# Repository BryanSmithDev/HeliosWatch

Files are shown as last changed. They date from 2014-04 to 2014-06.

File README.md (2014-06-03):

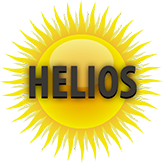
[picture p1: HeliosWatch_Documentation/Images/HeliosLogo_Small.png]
Helios
Helios Watch
==========
This project, dubbed Helios (God of Day/Night Cycle or God of the Sun), is based off of Tortuga's RetroWatch to create a Bluetooth enabled smartwatch using an Arduino that will pair with your Android device. Once paired, the smart watch can not only display the time and date, but notifications from your Android device as well. Additionally, the the watch can also display RSS feeds and system information, all of which can be filtered from the Android app designed for the watch. Modifications from Tortuga's RetroWatch include, a larger screen, larger battery, vibration (haptic feedback), and internal battery charging while maintaining serial connection.

[How to make the Helios Watch](http://www.mcs.uvawise.edu/wiki/index.php/Bluetooth_Smartwatch_for_Android_-_Bryan_Smith)

[University of Virginia's College at Wise - Department of Mathmatics and Computer Science](http://www.mcs.uvawise.edu/)

[AI and Robotics - Spring 2014](http://www.mcs.uvawise.edu/wiki/index.php/CSC4150_-_AI_and_Robotics)

==========
##Below is the original RetroWatch readme
>
>retrowatch
>==========
>
>Retro watch is open source smart watch project using Arduino and Android.
>
>
>
>==========
>[How-To: RetroWatch 제작방법 - 상세버전 (한글)](http://www.hardcopyworld.com/ngine/aduino/index.php/archives/376)
>
>[RetroWatch 안드로이드 앱 사용방법](http://www.hardcopyworld.com/ngine/android/index.php/archives/192)
>
>
>[How-To: Make your own smart watch (ENG)](http://www.hardcopyworld.com/ngine/aduino/index.php/archives/670) - >translated by Chang-Han Jeon.
>
>
>==========
>Do you want to post feedback, bugreport, suggestion or question? Use below links:
>
>[Forum: ](http://www.hardcopyworld.com/ngine/index.php/board/free-board)
>
>[QnA: ](http://www.hardcopyworld.com/ngine/index.php/board/qna)
>
>Email : godstale@hotmail.com

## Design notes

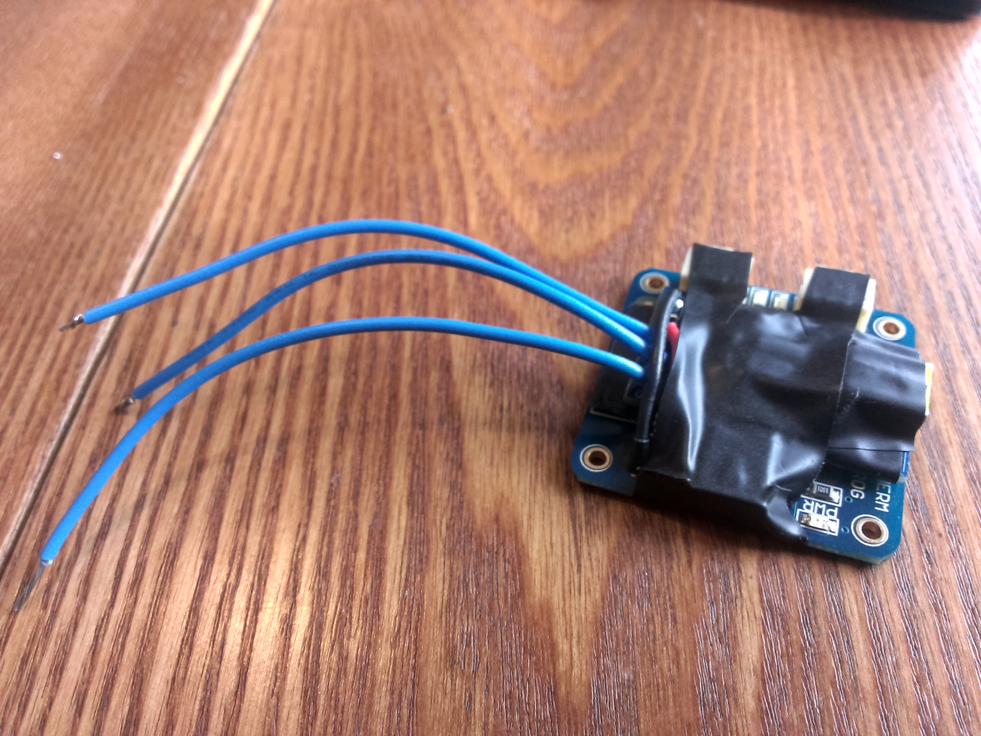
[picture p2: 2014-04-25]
HeliosWatch_Documentation/Images/PowerSupply6.jpg

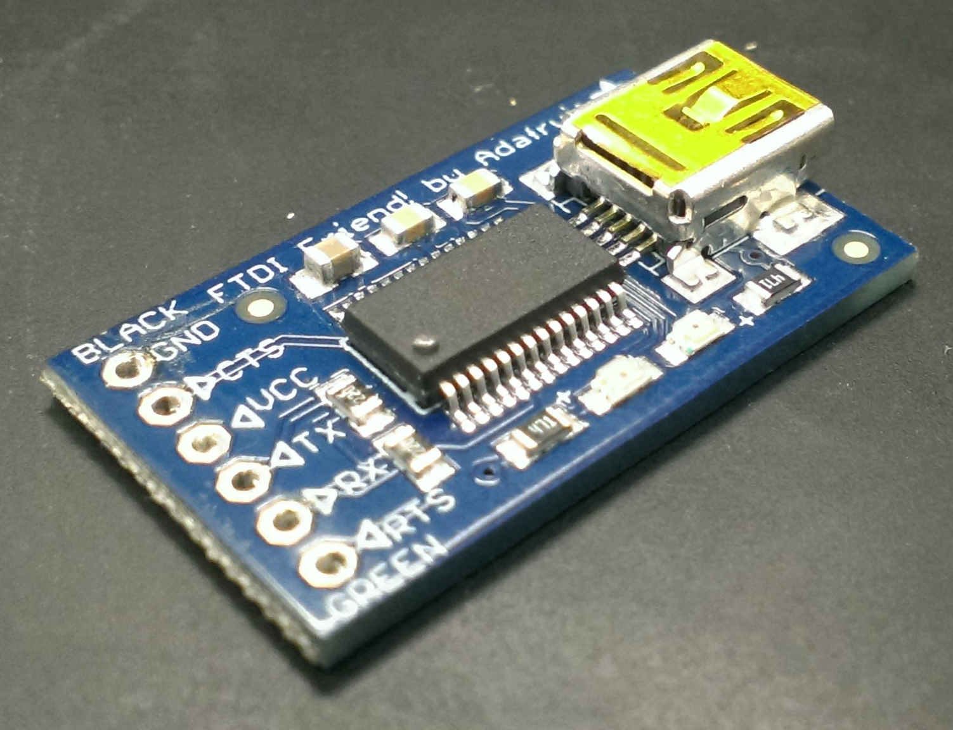
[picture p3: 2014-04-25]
HeliosWatch_Documentation/Images/FTDIPrep2.png

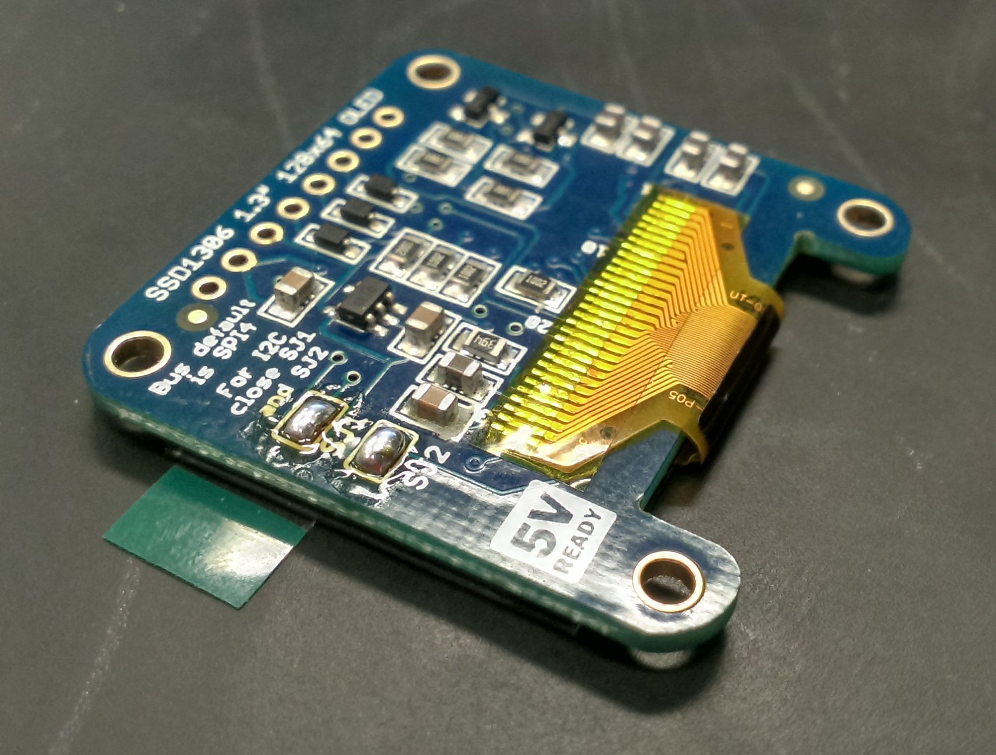
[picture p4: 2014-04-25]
HeliosWatch_Documentation/Images/DisplayPrep2.png

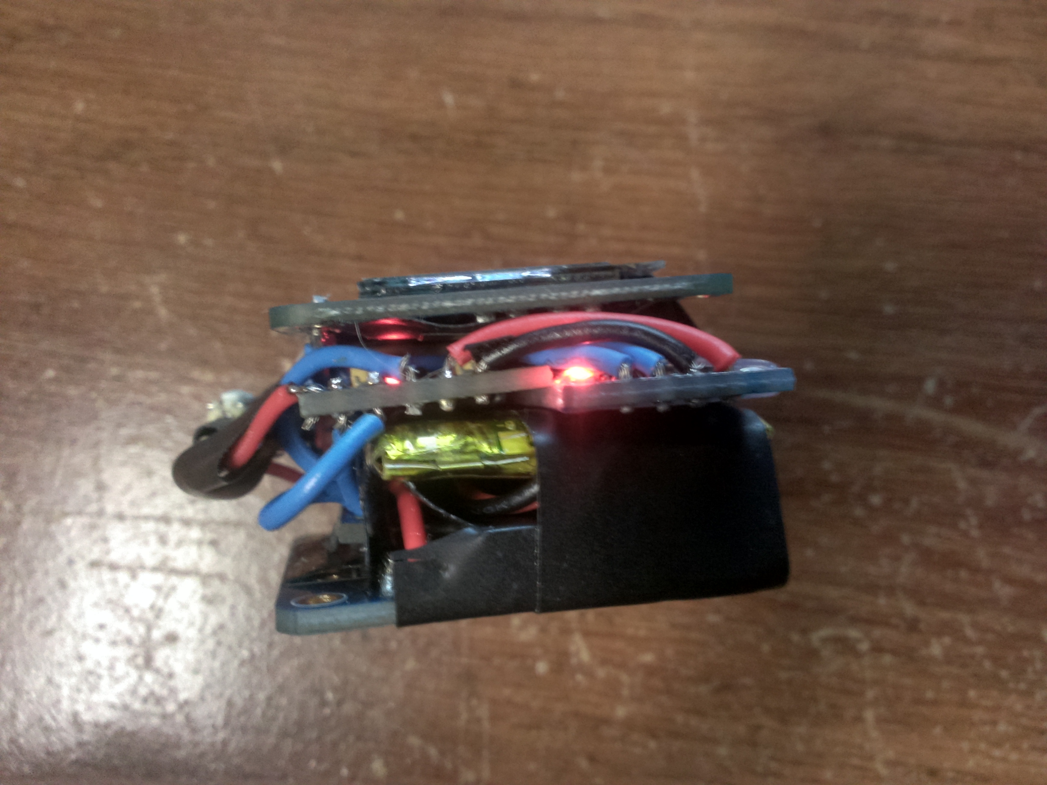
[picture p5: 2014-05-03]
HeliosWatch_Documentation/Images/watchLeftSide.jpg

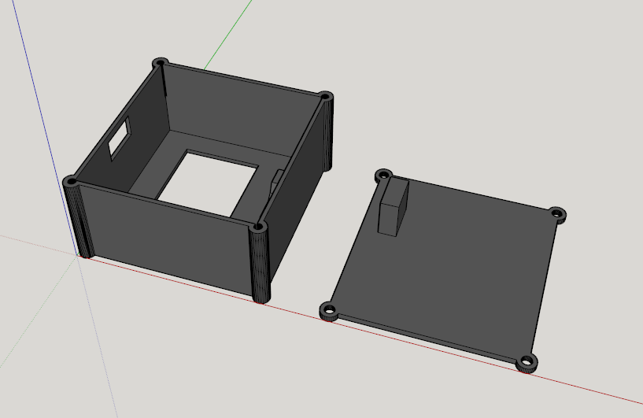
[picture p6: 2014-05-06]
HeliosWatch_Documentation/Images/helios3DcaseModel.png

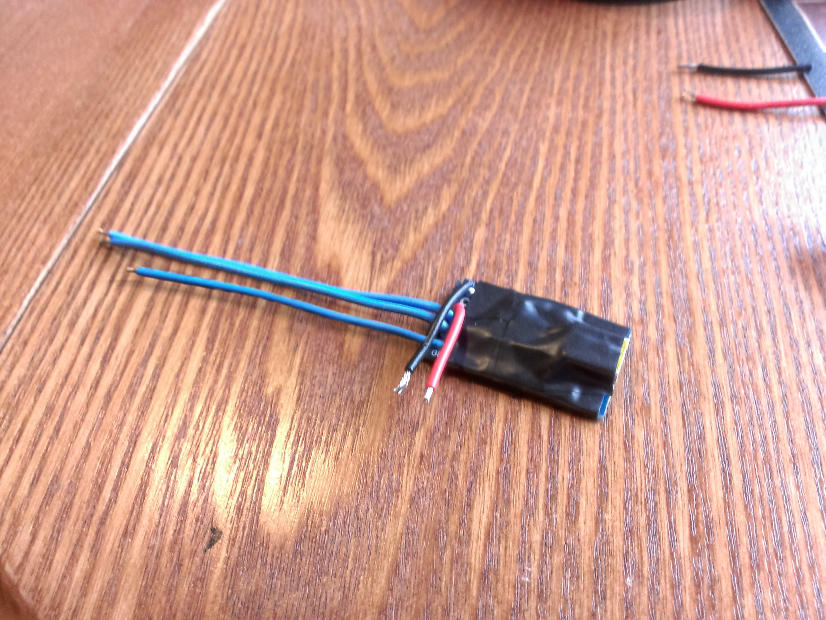
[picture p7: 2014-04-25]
HeliosWatch_Documentation/Images/PowerSupply3.jpg

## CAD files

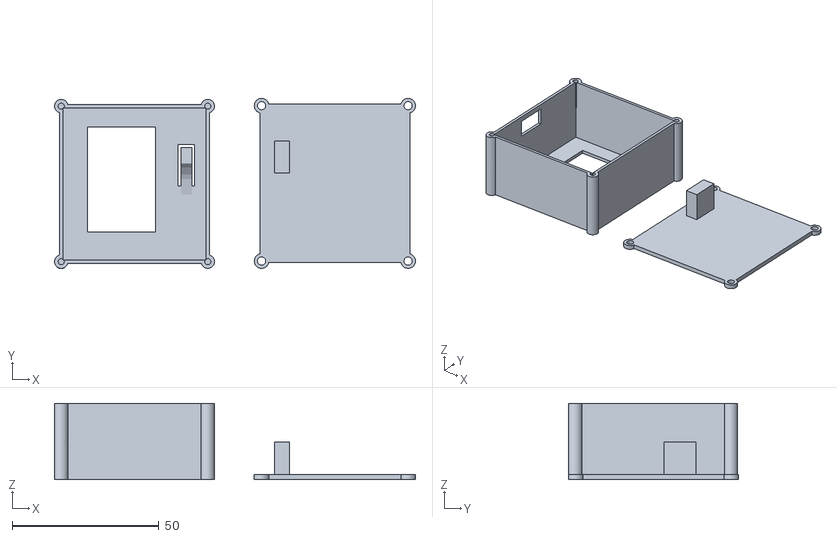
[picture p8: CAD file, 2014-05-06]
HeliosWatch_Documentation/Misc/HeliosCase.stl
123.2 x 58.1 x 26.0

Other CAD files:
HeliosWatch_Documentation/Misc/HeliosCase.skp

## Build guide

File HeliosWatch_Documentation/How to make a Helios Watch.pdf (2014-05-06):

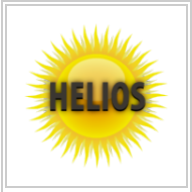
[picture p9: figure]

Helios Watch Logo

Helios Watch Completed (No Case)

# Bluetooth Smartwatch for Android - Bryan Smith

From MCS Wiki

## Contents

1 Project Description
2 Features / Specifications 3 Parts
3.1 Required
3.2 Tools / Misc
4 Assembly
4.1 Part Preparations
4.2 Power Supply Assembly
4.3 Watch Assembly
5 Code Base
5.1 Installing FTDI Drivers (Windows & Mac Only) 5.2 Installing Graphics & Display Libraries
5.3 Compile / Upload
6 Android App
7 Usage
8 3D Printed Case

## Project Description

This project, dubbed Helios (God of Day/Night Cycle or God of the Sun), is based off of Tortuga's RetroWatch (http://www.hardcopyworld.com/ngine/aduino/index.php/archives/670) to create a Bluetooth enabled smartwatch using an Arduino that will pair with your Android device. Once paired, the smart watch can not only display the time and date, but notifications from your Android device as well. Additionally, the the watch can also display RSS feeds and system information, all of which can be filtered from the Android app designed for the watch. Modifications from Tortuga's RetroWatch (http://www.hardcopyworld.com/ngine/aduino/index.php/archives/670) include, a larger screen, larger battery, vibration (haptic feedback), and internal battery charging while maintaining serial connection.

## Features / Specifications

Processor : ATmega328 – 3.3v(8MHz. Memory : 32KB Flash (2KB is shared for Bootloader), 2KB RAM, 1KB EEPROM.

Size : Width x Height x Depth = 45mm x 43mm x 26mm (Without case).
Battery : LiPo 500mAh(Around 24 to 25 hours of battery life.
Pairs via Bluetooth to Android Device running custom App.
Supports notifications, system info, RSS feed, and message filtering. Multiple clock faces.

Haptic Feedback (Vibration)
Open Source

## Parts

Required

1. Monochrome 1.3" 128x64 OLED graphic display (http://www.adafruit.com/products/938)
2. Lithium Ion Polymer Battery - 3.7v 500mAh (http://www.adafruit.com/products/1578)
3. USB LiIon/LiPoly charger - v1.2 (http://www.adafruit.com/products/259)
4. FTDI Friend + extras (http://www.adafruit.com/products/284)
5. Vibrating Mini Motor Disc (http://www.adafruit.com/products/1201) (Optional)
6. JST-PH Battery Extension Cable (http://www.adafruit.com/products/1131) (Optional. Needed for the Male JST end. However, LiPo Charger may come with one.)
7. Arduino Pro Mini 328 - 3.3V/8MHz (https://www.sparkfun.com/products/11114)
8. HC-06 Bluetooth Module (http://www.amazon.com/gp/product/B00DQ4A7O6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) or Bluetooth SMD Module - RN-42 (http://www.amazon.com/gp/product/B00DQ4A7O6) (https://www.sparkfun.com/products/10253)
9. Resistor 10K Ohm 1/6th Watt PTH - 20 pack (https://www.sparkfun.com/products/11508)
10. Momentary Reset Switch SMD (https://www.sparkfun.com/products/8229)
11. USB Cable A/MiniB (http://www.adafruit.com/products/260)

Tools / Misc

Soldering Iron Wire (Stranded 22 Gauge is what I used.)

3D Printer and ABS Filament in order to print the watch case. (Optional) Electrical tape.
A solder removal device such as a Solder Sucker. (optional)

A velcro strip or other materialfor the watch band.

## Assembly

Part Preparations

Some of the parts will need to be prepared before we begin assembling. First is the display. The display from AdaFruit is able to perform in two modes, SPI and I2C. By default, the display is set to use SPI. However, for this project it is recommended to use I2C. The difference between SPI and I2C for simplicity sake, is that I2C requires less cables (but is slower). The speed is not an issue for this project and the less cables the better for space efficiency. Next is the battery. The cable attached to the battery from the factory is much longer than we will need. So I removed some of the cable to save room and make everything cleaner. Lastly, the FTDI Friend may come with a header installed on the board. This takes up a lot of room, so I removed it.

Display
To set the display to I2C solder both SJ1 and SJ2 pads on the back of the display.
For more info, checkout the Adafruit page for this display - Here (http://www.adafruit.com/products/938)
Before. | After.

Battery
I recommend removing some of the battery cable as it takes up precious space. I left about an inch or an inch and a half of cable left, however I could have taken off more and been okay. I still had some I had to wrap under the battery when assembling. Use the pictures below for reference.
Before. | After.

FTDI Friend
I recommend removing the header from the FTDI friend as it takes up precious space. Use a Solder Sucker other method to remove the solder from the header to take it off. This guide will assume that you complete this step. It has not been tested with the header on. If the header is left on it may not fit in the case.
Before. | After.

Bluetooth Module
Depending on the Bluetooth module you use, there may be a header that needs to be removed similar to the FTDI Friend above. If using the HC-06 it will more than likely come with a header already attached that will need removing. Use a Solder Sucker other method to remove the solder from the header to take it off.

Now that you have all of the parts prepared, we will begin assembling.

Power Supply Assembly

First we will build the Power supply. These steps are quite detailed in comparison to most of the guide as the placement and construction of this section is important. A wire diagram is below that you can use for reference.

Power Supply
The power supply will handle most of the power related functions of the watch. The battery will be housed here and power will leave the power supply to go power the

Arduino, the display, etc. Also, battery recharging and serial data connection will be combined into one USB port for convenience.
1. First, solder five wires to the FTDI Friend with the wire stemming from the top. One for power, ground, transfer, receive, and reset. I cut these wires to be about 2 or 3 inches, they will be trimmed to the correct length later in the guide. Trim excess solder/wire from the bottom of the FTDI Friend. See image 1 below.
2. Set the FTDI Friend on top of the LiPo charger in an orientation that allows the LOAD,BAT,and STAT pads on the LiPo charger to still be roughly seen, while keeping the FTDI Friends USB port pointing out. This should put the pins of the FTDI Friend roughly across from the DCIN pins on the LiPo charger. Then bend the positive and ground wires over toward the DCIN pins on the LiPo charger. See image 2 below.
3. Next, wrap the FTDI friend in electrical tape. This will protect from short circuits because the FTDI friend will be setting on top of the LiPo charger next. Make sure to put electrical tape on the bottom side of the FTDI friend covering the pins you just soldered. See image 3 and 4 below.
4. Trim the positive and ground wires about a quarter of an inch after they pass the DCIN pins on the LiPo charger, then solder them into the corresponding DCIN pins on the LiPo Charger. See image 5 below.
5. Use some electrical tape to hold the FTDI Friend in place. In doing so you can also cover up the USB port of the LiPo charger (NOT the FTDI Friend) so you won't get confused. Power will be sent to the LiPo charger through the FTDI Friend now. Make sure to not cover up the JST battery ports on the other side of the LiPo charger though. See image 6 below.
6. Finally, plug in the battery to the LiPo charger (the left JST port if you have the ports facing you) and place the battery on top of the FTDI Friend, curling up any extra cable (hopefully not much if any extra left from the prep step) underneath the battery. Use electrical tape to secure the battery in place. See image 7 below.
This completes the power supply for now.

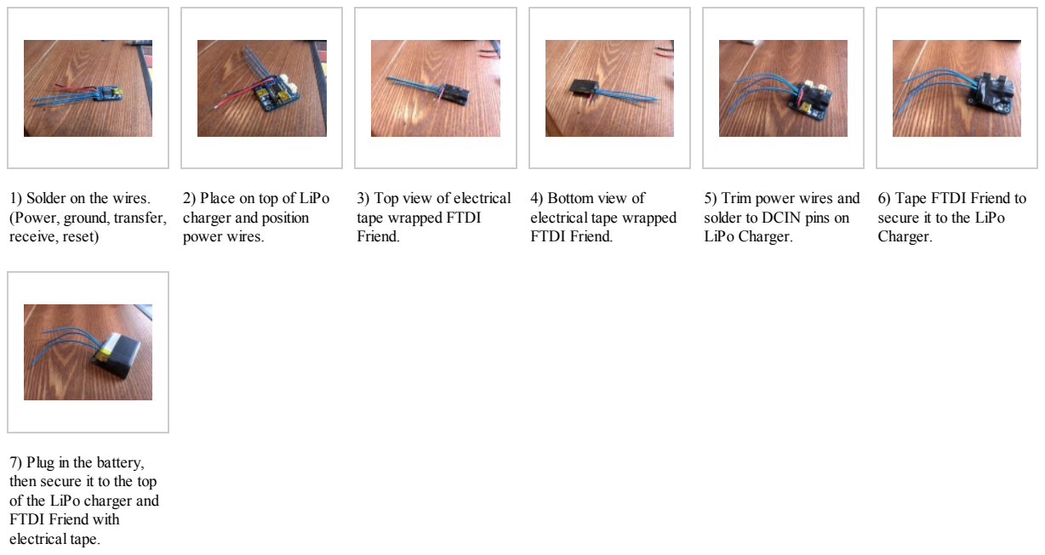
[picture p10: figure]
1) Solder on the wires. (Power, ground, transfer, receive, reset); 2) Place on top of LiPo charger and position power wires.; 3) Top view of electrical tape wrapped FTDI Friend.; 4) Bottom view of electrical tape wrapped FTDI Friend.; 5) Trim power wires and solder to DCIN pins on LiPo Charger.; 6) Tape FTDI Friend to secure it to the LiPo Charger.; 7) Plug in the battery, then secure it to the top of the LiPo charger and FTDI Friend with electrical tape.

Watch Assembly

Now that the power supply is done, the rest of the watch can be put together. The majority of the work that is left is the straight forward soldering of wires to the correct pins that are laid out in the diagrams below.

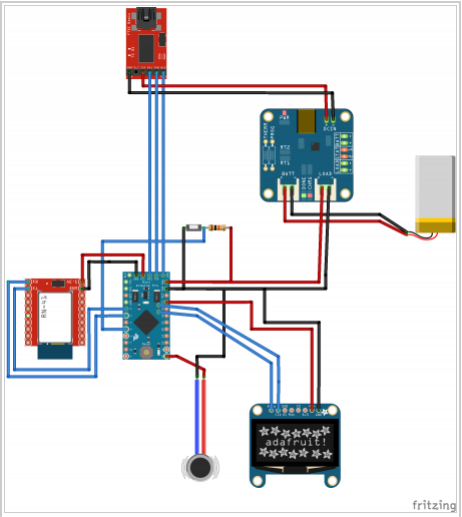
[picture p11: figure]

Wire Diagram(Click for enlarged version.)

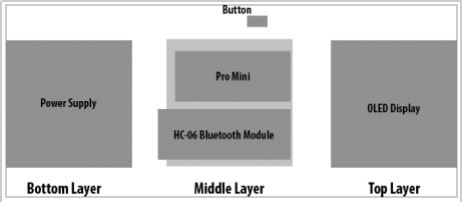
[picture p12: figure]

A Top Down View of the 3 Watch Layers

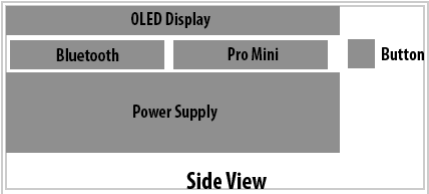
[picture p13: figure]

A Side View of the 3 Watch Layers

Recommended Steps to Assemble (Use diagrams for reference):
1. Read the entire guide. Especially the Additional Notes below. Get familiar with the diagrams and layouts.
2. Power Supply (See above.)
3. Connect Bluetooth to Arduino
4. Connect Button to Arduino (Only its digital pin)
5. Connect the Display to the Arduino
6. Set the components on top of the power supply. Make sure the USB port for the power supply is facing you. This also means the battery ports are on the right.
7. Combine the Display, Button, and vibration motor power and ground wires with the batteries power and ground.
8. Connect the combined power and ground to the Arduino.
9. Place the vibration motor anywhere it willfit. Such as on the side or under the display.
10. Use electrical tape to hold down the display to hold all of the parts together with the power supply.

Additional Notes Make sure to use tape on the top and/or bottom ofsome parts to keep them from shorting each other out. Such as the bottom of the display.

Connecting Arduino Pro Mini and Bluetooth Module
BT -> Arduino Pro Mini
VCC -> VCC

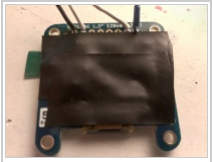
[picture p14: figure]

Make sure to cover parts with tape to keep them from shorting out since they sit atop one another. As seen here with the back of the OLED Display

GND -> GND
TX -> Digital 2
RX -> Digital 3
(Must use pins digital 2 & 3. Do not change. These are special external interrupt pins for the Arduino) Connecting Arduino Pro Mini to OLED Display (I2C)
OLED -> Arduino Pro mini :
GND -> GND
VIN -> VCC
DATA -> Analog 4
CLK -> Analog 5
(Must use pins analog 4 & 5. Do not change. These are special SDA and SCL I2C communication pins for the Arduino)

## Code Base

You can download Helios Watch Arduino source on GitHub.

Helios Code (Github) (https://github.com/BryanSmithDev/HeliosWatch)

Click "Download ZIP" to download and unzip it. The Source Code is divided into folders, one for Arduino and the other for the Android App. Before you will be able to compile the Arduino source you may need to installsome drivers and libraries.

Installing FTDI Drivers (Windows & Mac Only)

Windows and Mac OS required drivers in order to communicate to the Arduino through the FTDI friend. Linux has the drivers built in.

Download the drivers here (http://www.ftdichip.com/Drivers/VCP.htm) .

If you need more help installing the drivers, go here (https://learn.adafruit.com/ftdi-friend/installing-ftdi-drivers) .

Installing Graphics & Display Libraries

In order to draw the images, shapes and fonts on the OLED Display you need a graphic library. You must install Adafruit_SSD1306 display library (if using the display listed in Parts) and the Adafruit-GFX-Library. Click "Download ZIP" button on the down-right in the link to download and copy the library folder to libraries folder for your Arduino IDE. If you need help installing Arduino IDE Libraries, click here (http://arduino.cc/en/Guide/Libraries) . (You may need to rename the folders when placing them in the Libraries folder. characters like '-' are not allowed in the folder name. Simple replace them with '_')

(According to your development environment, Adafruit library conflicts with Robot_xxx library. In this case, backup and delete Robot_xxx libraries from Arduino library folder.)

Adafruit_SSD1306 Library (https://github.com/adafruit/Adafruit_SSD1306)
Adafruit-GFX Library (https://github.com/adafruit/Adafruit-GFX-Library)

Compile / Upload

If you completed the steps above correctly, you should now be able to compile and upload the source code to the Arduino.

Steps to Compile and Upload.
1. Open HeliosWatchArduino.ino in the Arduino IDE
2. Plug in the watch.
3. Set the Board to Arduino Pro Mini 3.3v 8Mhz ATmega328 (May vary in different IDE versions)
4. Select the Port number representing the watch.
5. Press Upload

If everything worked correctly, you should soon seen the display come on and show a clock at 0:00. It is now ready for pairing with the Android App.

## Android App

Most of this information is derived from Tortuga's RetroWatch Guide (http://www.hardcopyworld.com/ngine/aduino/index.php/archives/670) and modified to fit Helios Watch's modifications and for improved English readability.

Helios Watch Android Source code is included on the GitHub along with the Arduino Source code. If you downloaded the source code here then you already have the Android App source code. It is located in the HeliosWatch_Android folder. However the source code is not needed unless you need to modify the app due to changes you made in the watch assembly process (e.x. used a different pin for the Vibration motor.). You only need to download the app to you phone from below.

Download the Helios Watch App here:
Helios Watch (Android 4.3+) (https://github.com/BryanSmithDev/HeliosWatch/raw/Helios/HeliosWatch_Android/HeliosWatch.apk)
Helios Watch LE (Android versions lower than 4.3) (https://github.com/BryanSmithDev/HeliosWatch/raw/Helios/HeliosWatch_Android/HeliosWatchLE.apk)

App Tabs:

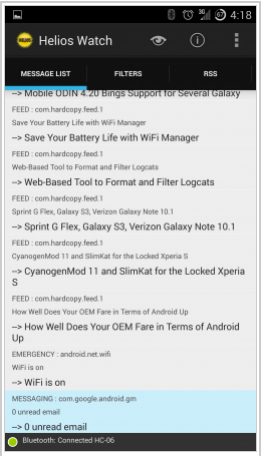
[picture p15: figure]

Message List Tab. This allows you to find and select notifications to send to the watch via filters.

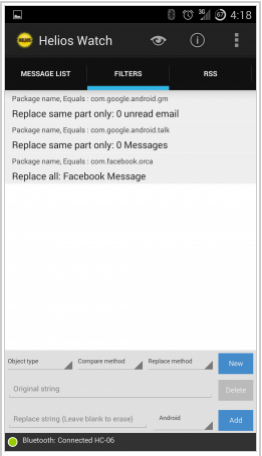
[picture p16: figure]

Filters Tab. This allows you to create, edit, or delete filters. Filters control what is displayed on the watch and where the data comes from.

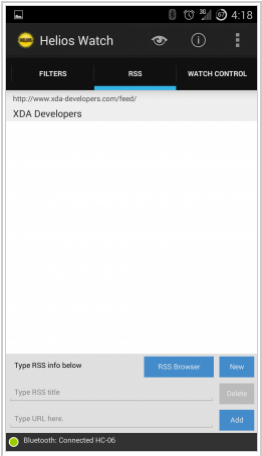
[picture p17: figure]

RSS Tab. RSS Feeds are added here to allow them to show up in the Message List.

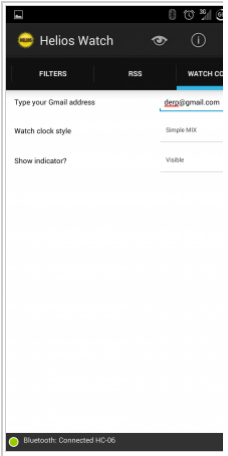
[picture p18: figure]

Watch Control Tab. Allows you to change watch faces, and notification indicator viability, etc.

Message List Tab: Messages are the information collected from the app. Every message is inactivated except for emergency messages. Inactivated messages are not sent to the watch. By touching a message, you can create a filter for that message or messages from the same package.
Filter Tab: The Helios Watch app controls all notifications sent to the watch by filtering. You can add, edit, and delete filters in this tab. it also allows string manipulation to edit what shows up on the watch compared to what was given from the notification.
RSS Tab: You can add, edit, and remove RSS feeds here. You can show notifications on the watch based off of RSS feeds. Watch Control Tab: Allows you to change watch faces, and notification indicator viability, etc. If you put your Gmail account here, unread messages are added in the

message list.

The Helios Watch app collects three kinds of data:
Notification: A notification that is registered in the Android Status Bar. The app uses the Notification Service to collect notifications (Only Android 4.3 or higher). If your are using Android versions lower than 4.3 then use the Helios Watch LE app.
System info: The system info of the phone such as battery status, mobile data connection status, WiFistatus, and recharging progress. In addition, if you register a Gmail account, it counts unread e-mails.
RSS feed: If you set RSS title and URL, it periodically read RSS data and sends it to the Message List.

Other minor features:
Up to 65 icons available to use for notifications on the watch.
All information is updated to the watch every 30 minutes.
The Helios Watch service runs in background even if you shut the app.

For a long in-depth walkthrough of using the app, read Tortuga's RetroWatch App User Guide (http://www.hardcopyworld.com/ngine/aduino/index.php/archives/722) . It still applies to Helios Watch.

## Usage

Once you have the code uploaded to the Arduino and the Android App installed on your device, you are ready to use the watch. Turn on bluetooth on your device and pair with the module (If it asks for a pin try 1234 or 0000). Next, start the Helios Watch app. If on Android 4.3+ press the second icon in the action bar, which is the 'i' with a circle around it. Then make sure Helios Watch is selected and then hit the back button. Then choose the first action bar item and select the bluetooth module that is already paired. If you can't find it, check the power and the bluetooth module. Or choose "device scan"menu to scan manually.

If the connection succeeded, you should see "Connected" in connectivity the display area at the bottom. Touch the action bar menu(…) and choose "Force Watch Sync". This willforce the phone data to display the time and messages on the watch. You are now allset up and can start making filters to show your notifications.

Below are some pictures of my completed watch:

Top View of my Helios Watch

Top Side of my Helios Watch

Right Side of my Helios Watch

Bottom Side of my Helios Watch

Left Side of my Helios Watch

My Helios Watch

The Helios Watch Case Model in SketchUp | The Helios Watch Case | The Helios Watch Case

## 3D Printed Case

The case for Helios Watch may be 3D printed and using hot glue or other adhesive to attach velcro to the back for the watch band. Due to the fact that all Helios Watches made will vary from person to person, since we are not robots mass producing these with perfect accuracy, I cannot guarantee that the case willfit your watch. So some modification of the case may be required. The STL file for 3D printing, and the SketchUp 3D file for if you need to make your own modifications, are included in the GitHub Repository (https://github.com/BryanSmithDev/HeliosWatch) in the documentation folder. They are also linked below.

Downloads:
Helios Case - STL (https://github.com/BryanSmithDev/HeliosWatch/raw/Helios/HeliosWatch_Documentation/Misc/HeliosCase.stl)
Helios Case - SketchUp File (https://github.com/BryanSmithDev/HeliosWatch/raw/Helios/HeliosWatch_Documentation/Misc/HeliosCase.skp)

Retrieved from "http://www.mcs.uvawise.edu/wiki/index.php?title=Bluetooth_Smartwatch_for_Android_-_Bryan_Smith&oldid=2711"

This page was last modified on 6 May 2014, at 22:53.

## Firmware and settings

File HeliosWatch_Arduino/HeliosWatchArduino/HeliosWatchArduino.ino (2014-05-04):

/*
 This project, dubbed Helios (God of Day/Night Cycle or God of the
 Sun), is based off of Tortuga's RetroWatch to create a Bluetooth
 enabled smart watch using an Arduino that will pair with your Android
 device. Once paired, the smart watch can not only display the time
 and date, but notifications from your Android device as well.
 Additionally, the the watch can also display RSS feeds and system
 information, all of which can be filtered from the Android app designed
 for the watch. Modifications from Tortuga's RetroWatch include,
 a larger screen, larger battery, vibration (haptic feedback),
 and internal battery charging while maintaining serial connection.

 Below is the RetroWatch Info
*/
/*
    RetroWatch Arduino is a part of open source smart watch project.
    Copyright (C) 2014  Suh Young Bae

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
    You should have received a copy of the GNU General Public License
    along with this program.  If not, see [http://www.gnu.org/licenses/].
*/
/*
Retro Watch Arduino v1.0

  Get the latest version, android host app at
  ------> https://github.com/godstale/retrowatch
  ------> or http://www.hardcopyworld.com

Written by Suh Young Bae (godstale@hotmail.com)
All text above, and the first splash screen(Adafruit) must be included in any redistribution
*/

#include <SPI.h>
#include <avr/pgmspace.h>
#include <Wire.h>
#include <SoftwareSerial.h>
#include <Adafruit_GFX.h>
#include <Adafruit_SSD1306.h>
#include <math.h>
#include "bitmap.h"

///////////////////////////////////////////////////////////////////
//----- OLED instance
#define OLED_RESET 4
Adafruit_SSD1306 display(OLED_RESET);

#if (SSD1306_LCDHEIGHT != 64)
#error("Height incorrect, please fix Adafruit_SSD1306.h!");
#endif
///////////////////////////////////////////////////////////////////

///////////////////////////////////////////////////////////////////
//----- BT instance
SoftwareSerial BTSerial(2, 3); //Connect HC-06, RX, TX
///////////////////////////////////////////////////////////////////

//----- Bluetooth transaction parsing
#define TR_MODE_IDLE 1
#define TR_MODE_WAIT_CMD 11
#define TR_MODE_WAIT_MESSAGE 101
#define TR_MODE_WAIT_TIME 111
#define TR_MODE_WAIT_ID 121
#define TR_MODE_WAIT_COMPLETE 201

#define TRANSACTION_START_BYTE 0xfc
#define TRANSACTION_END_BYTE 0xfd

#define CMD_TYPE_NONE 0x00
#define CMD_TYPE_RESET_EMERGENCY_OBJ 0x05
#define CMD_TYPE_RESET_NORMAL_OBJ 0x02
#define CMD_TYPE_RESET_USER_MESSAGE 0x03

#define CMD_TYPE_ADD_EMERGENCY_OBJ 0x11
#define CMD_TYPE_ADD_NORMAL_OBJ 0x12
#define CMD_TYPE_ADD_USER_MESSAGE 0x13

#define CMD_TYPE_DELETE_EMERGENCY_OBJ 0x21
#define CMD_TYPE_DELETE_NORMAL_OBJ 0x22
#define CMD_TYPE_DELETE_USER_MESSAGE 0x23

#define CMD_TYPE_SET_TIME 0x31
#define CMD_TYPE_REQUEST_MOVEMENT_HISTORY 0x32
#define CMD_TYPE_SET_CLOCK_STYLE 0x33
#define CMD_TYPE_SET_INDICATOR 0x34
#define CMD_TYPE_SET_VIBRATION 0x35

#define CMD_TYPE_PING 0x51
#define CMD_TYPE_AWAKE 0x52
#define CMD_TYPE_SLEEP 0x53
#define CMD_TYPE_REBOOT 0x54

byte TRANSACTION_POINTER = TR_MODE_IDLE;
byte TR_COMMAND = CMD_TYPE_NONE;

//----- Message item buffer
#define MSG_COUNT_MAX 7
#define MSG_BUFFER_MAX 19
unsigned char msgBuffer[MSG_COUNT_MAX][MSG_BUFFER_MAX];
char msgParsingLine = 0;
char msgParsingChar = 0;
char msgCurDisp = 0;

//----- Emergency item buffer
#define EMG_COUNT_MAX 3
#define EMG_BUFFER_MAX 19
char emgBuffer[EMG_COUNT_MAX][EMG_BUFFER_MAX];
char emgParsingLine = 0;
char emgParsingChar = 0;
char emgCurDisp = 0;

//----- Time
#define UPDATE_TIME_INTERVAL 60000
byte iMonth = 1;
byte iDay = 1;
byte iWeek = 1;    // 1: SUN, MON, TUE, WED, THU, FRI,SAT
byte iAmPm = 0;    // 0:AM, 1:PM
byte iHour = 0;
byte iMinutes = 0;
byte iSecond = 0;

#define TIME_BUFFER_MAX 6
char timeParsingIndex = 0;
char timeBuffer[6] = { -1, -1, -1, -1, -1, -1};
PROGMEM const char* weekString[] = {"", "Sun", "Mon", "Tue", "Wed", "Thu", "Fri", "Sat"};
PROGMEM const char* ampmString[] = {"AM", "PM"};

//----- Display features
#define DISPLAY_MODE_START_UP 0
#define DISPLAY_MODE_CLOCK 1
#define DISPLAY_MODE_EMERGENCY_MSG 2
#define DISPLAY_MODE_NORMAL_MSG 3
#define DISPLAY_MODE_IDLE 11
byte displayMode = DISPLAY_MODE_START_UP;

#define CLOCK_STYLE_SIMPLE_ANALOG  0x01
#define CLOCK_STYLE_SIMPLE_DIGIT  0x02
#define CLOCK_STYLE_SIMPLE_MIX  0x03
byte clockStyle = CLOCK_STYLE_SIMPLE_MIX;

#define INDICATOR_ENABLE 0x01
boolean updateIndicator = true;

#define VIBRATION_ENABLE 0x01
boolean vibration = true;

byte centerX = 64;
byte centerY = 32;
byte iRadius = 28;

#define IDLE_DISP_INTERVAL 60000
#define CLOCK_DISP_INTERVAL 60000
#define EMERGENCY_DISP_INTERVAL 5000
#define MESSAGE_DISP_INTERVAL 3000
unsigned long prevClockTime = 0;
unsigned long prevDisplayTime = 0;

unsigned long next_display_interval = 0;
unsigned long mode_change_timer = 0;
#define CLOCK_DISPLAY_TIME 300000
#define EMER_DISPLAY_TIME 10000
#define MSG_DISPLAY_TIME 5000

//----- Button control
int buttonPin = 5;
boolean isClicked = false;

//----- Vibration Motor Control
int motorPin = 10;
int notificationVibrateInterval = 500;



void setup()   {
  //Serial.begin(9600);    // Do not enable serial. This makes serious problem because of shortage of RAM.
  pinMode(buttonPin, INPUT);  // Defines button pin

  pinMode(motorPin, OUTPUT);

  init_emg_array();
  init_msg_array();

  //----- by default, we'll generate the high voltage from the 3.3v line internally! (neat!)
  display.begin(SSD1306_SWITCHCAPVCC, 0x3D);  // initialize with the I2C addr 0x3D (for the 128x64)
  display.display();    // show splashscreen
  delay(1000);
  drawStartUp();    // Show RetroWatch Logo
  centerX = display.width() / 2;
  centerY = display.height() / 2;
  iRadius = centerY - 2;

  BTSerial.begin(9600);  // set the data rate for the BT port
}


void loop() {
  boolean isReceived = false;
  unsigned long current_time = 0;

  // Get button input
  if (digitalRead(buttonPin) == LOW) {
    isClicked = LOW;
    if (vibration) digitalWrite(motorPin, HIGH);
  } else {
    if (vibration) digitalWrite(motorPin, LOW);
  }

  // Receive data from remote and parse
  isReceived = receiveBluetoothData();

  // Update clock time
  current_time = millis();
  updateTime(current_time);

  // Display routine
  onDraw(current_time);

  // If data doesn't arrive, wait for a while to save battery
  if (!isReceived)
    delay(300);
}




///////////////////////////////////
//----- Utils
///////////////////////////////////
void init_msg_array() {
  for (int i = 0; i < MSG_COUNT_MAX; i++) {
    for (int j = 0; j < MSG_BUFFER_MAX; j++) {
      msgBuffer[i][j] = 0x00;
    }
  }
  msgParsingLine = 0;
  msgParsingChar = 0;    // First 2 byte is management byte
  msgCurDisp = 0;
}

void init_emg_array() {
  for (int i = 0; i < EMG_COUNT_MAX; i++) {
    for (int j = 0; j < EMG_BUFFER_MAX; j++) {
      emgBuffer[i][j] = 0x00;
    }
  }
  emgParsingLine = 0;
  emgParsingChar = 0;    // First 2 byte is management byte
  emgCurDisp = 0;
}

void vibrate() {
  if (vibration) {
    digitalWrite(motorPin, HIGH);
    delay(notificationVibrateInterval);
    digitalWrite(motorPin, LOW);
    delay(100);
    digitalWrite(motorPin, HIGH);
    delay(notificationVibrateInterval);
  }
}

///////////////////////////////////
//----- Time functions
///////////////////////////////////
void setTimeValue() {
  iMonth = timeBuffer[0];
  iDay = timeBuffer[1];
  iWeek = timeBuffer[2];    // 1: SUN, MON, TUE, WED, THU, FRI,SAT
  iAmPm = timeBuffer[3];    // 0:AM, 1:PM
  iHour = timeBuffer[4];
  iMinutes = timeBuffer[5];
}

void updateTime(unsigned long current_time) {
  if (iMinutes >= 0) {
    if (current_time - prevClockTime > UPDATE_TIME_INTERVAL) {
      // Increase time
      iMinutes++;
      if (iMinutes >= 60) {
        iMinutes = 0;
        iHour++;
        if (iHour > 12) {
          iHour = 1;
          (iAmPm == 0) ? iAmPm = 1 : iAmPm = 0;
          if (iAmPm == 0) {
            iWeek++;
            if (iWeek > 7)
              iWeek = 1;
            iDay++;
            if (iDay > 30) // Yes. day is not exact.
              iDay = 1;
          }
        }
      }
      prevClockTime = current_time;
    }
  }
  else {
    displayMode = DISPLAY_MODE_START_UP;
  }
}

///////////////////////////////////
//----- BT, Data parsing functions
///////////////////////////////////

// Parsing packet according to current mode
boolean receiveBluetoothData() {
  int isTransactionEnded = false;
  while (!isTransactionEnded) {
    if (BTSerial.available()) {
      byte c = BTSerial.read();

      if (c == 0xFF && TRANSACTION_POINTER != TR_MODE_WAIT_MESSAGE) return false;

      if (TRANSACTION_POINTER == TR_MODE_IDLE) {
        parseStartSignal(c);
      }
      else if (TRANSACTION_POINTER == TR_MODE_WAIT_CMD) {
        parseCommand(c);
      }
      else if (TRANSACTION_POINTER == TR_MODE_WAIT_MESSAGE) {
        parseMessage(c);
      }
      else if (TRANSACTION_POINTER == TR_MODE_WAIT_TIME) {
        parseTime(c);
      }
      else if (TRANSACTION_POINTER == TR_MODE_WAIT_ID) {
        parseId(c);
      }
      else if (TRANSACTION_POINTER == TR_MODE_WAIT_COMPLETE) {
        isTransactionEnded = parseEndSignal(c);
      }

    }  // End of if(BTSerial.available())
    else {
      isTransactionEnded = true;
    }
  }  // End of while()
  return true;
}  // End of receiveBluetoothData()

void parseStartSignal(byte c) {
  //drawLogChar(c);
  if (c == TRANSACTION_START_BYTE) {
    TRANSACTION_POINTER = TR_MODE_WAIT_CMD;
    TR_COMMAND = CMD_TYPE_NONE;
  }
}

void parseCommand(byte c) {
  if (c == CMD_TYPE_RESET_EMERGENCY_OBJ || c == CMD_TYPE_RESET_NORMAL_OBJ || c == CMD_TYPE_RESET_USER_MESSAGE) {
    TRANSACTION_POINTER = TR_MODE_WAIT_COMPLETE;
    TR_COMMAND = c;
    processTransaction();
  }
  else if (c == CMD_TYPE_ADD_EMERGENCY_OBJ || c == CMD_TYPE_ADD_NORMAL_OBJ || c == CMD_TYPE_ADD_USER_MESSAGE) {
    TRANSACTION_POINTER = TR_MODE_WAIT_MESSAGE;
    TR_COMMAND = c;
    if (c == CMD_TYPE_ADD_EMERGENCY_OBJ) {
      emgParsingChar = 0;
      if (emgParsingLine >= MSG_COUNT_MAX || emgParsingLine < 0)
        emgParsingLine = 0;
    }
    else if (c == CMD_TYPE_ADD_NORMAL_OBJ) {
      msgParsingChar = 0;
      if (msgParsingLine >= MSG_COUNT_MAX || msgParsingLine < 0)
        msgParsingLine = 0;
    }
  }
  else if (c == CMD_TYPE_DELETE_EMERGENCY_OBJ || c == CMD_TYPE_DELETE_NORMAL_OBJ || c == CMD_TYPE_DELETE_USER_MESSAGE) {
    TRANSACTION_POINTER = TR_MODE_WAIT_COMPLETE;
    TR_COMMAND = c;
  }
  else if (c == CMD_TYPE_SET_TIME) {
    TRANSACTION_POINTER = TR_MODE_WAIT_TIME;
    TR_COMMAND = c;
  }
  else if (c == CMD_TYPE_SET_CLOCK_STYLE || c == CMD_TYPE_SET_INDICATOR || c == CMD_TYPE_SET_VIBRATION) {
    TRANSACTION_POINTER = TR_MODE_WAIT_ID;
    TR_COMMAND = c;
  }
  else {
    TRANSACTION_POINTER = TR_MODE_IDLE;
    TR_COMMAND = CMD_TYPE_NONE;
  }
}

void parseMessage(byte c) {
  if (c == TRANSACTION_END_BYTE) {
    processTransaction();
    TRANSACTION_POINTER = TR_MODE_IDLE;
  }

  if (TR_COMMAND == CMD_TYPE_ADD_EMERGENCY_OBJ) {
    if (emgParsingChar < EMG_BUFFER_MAX) {
      if (emgParsingChar > 1) {
        emgBuffer[emgParsingLine][emgParsingChar] = c;
      }
      emgParsingChar++;
    }
    else {
      TRANSACTION_POINTER = TR_MODE_WAIT_COMPLETE;
    }
  }
  else if (TR_COMMAND == CMD_TYPE_ADD_NORMAL_OBJ) {
    if (msgParsingChar < MSG_BUFFER_MAX) {
      if (msgParsingChar > 1) {
        msgBuffer[msgParsingLine][msgParsingChar] = c;
      }
      msgParsingChar++;
    }
    else {
      TRANSACTION_POINTER = TR_MODE_WAIT_COMPLETE;
    }
  }
  else if (TR_COMMAND == CMD_TYPE_ADD_USER_MESSAGE) {
    // Not available yet.
    TRANSACTION_POINTER = TR_MODE_WAIT_COMPLETE;
  }
}

void parseTime(byte c) {
  if (TR_COMMAND == CMD_TYPE_SET_TIME) {
    if (timeParsingIndex >= 0 && timeParsingIndex < TIME_BUFFER_MAX) {
      timeBuffer[timeParsingIndex] = (int)c;
      timeParsingIndex++;
    }
    else {
      processTransaction();
      TRANSACTION_POINTER = TR_MODE_WAIT_COMPLETE;
    }
  }
}

void parseId(byte c) {
  if (TR_COMMAND == CMD_TYPE_SET_CLOCK_STYLE) {
    clockStyle = c;
    processTransaction();
  }
  else if (TR_COMMAND == CMD_TYPE_SET_INDICATOR) {
    if (c == INDICATOR_ENABLE)
      updateIndicator = true;
    else
      updateIndicator = false;
    processTransaction();
  }
  else if (TR_COMMAND == CMD_TYPE_SET_VIBRATION) {
    if (c == VIBRATION_ENABLE)
      vibration  = true;
    else
      vibration = false;
    processTransaction();
  }
  TRANSACTION_POINTER = TR_MODE_WAIT_COMPLETE;
}

boolean parseEndSignal(byte c) {
  if (c == TRANSACTION_END_BYTE) {
    TRANSACTION_POINTER = TR_MODE_IDLE;
    return true;
  }
  return false;
}

void processTransaction() {
  if (TR_COMMAND == CMD_TYPE_RESET_EMERGENCY_OBJ) {
    init_emg_array();//init_msg_array();
  }
  else if (TR_COMMAND == CMD_TYPE_RESET_NORMAL_OBJ) {
    init_msg_array();//init_emg_array();
  }
  else if (TR_COMMAND == CMD_TYPE_RESET_USER_MESSAGE) {
    // Not available yet.
  }
  else if (TR_COMMAND == CMD_TYPE_ADD_NORMAL_OBJ) {
    msgBuffer[msgParsingLine][0] = 0x01;
    msgParsingChar = 0;
    msgParsingLine++;
    if (msgParsingLine >= MSG_COUNT_MAX)
      msgParsingLine = 0;
    setNextDisplayTime(millis(), 0);  // update screen immediately
    vibrate();
  }
  else if (TR_COMMAND == CMD_TYPE_ADD_EMERGENCY_OBJ) {
    emgBuffer[emgParsingLine][0] = 0x01;
    emgParsingChar = 0;
    emgParsingLine++;
    if (emgParsingLine >= EMG_COUNT_MAX)
      emgParsingLine = 0;
    startEmergencyMode();
    setNextDisplayTime(millis(), 2000);
    vibrate();
  }
  else if (TR_COMMAND == CMD_TYPE_ADD_USER_MESSAGE) {
  }
  else if (TR_COMMAND == CMD_TYPE_DELETE_EMERGENCY_OBJ || TR_COMMAND == CMD_TYPE_DELETE_NORMAL_OBJ || TR_COMMAND == CMD_TYPE_DELETE_USER_MESSAGE) {
    // Not available yet.
  }
  else if (TR_COMMAND == CMD_TYPE_SET_TIME) {
    setTimeValue();
    timeParsingIndex = 0;
    setNextDisplayTime(millis(), 0);  // update screen immediately
  }
  if (TR_COMMAND == CMD_TYPE_SET_CLOCK_STYLE || CMD_TYPE_SET_INDICATOR) {
    setNextDisplayTime(millis(), 0);  // update screen immediately
  }
}

///////////////////////////////////
//----- Drawing methods
///////////////////////////////////

// Main drawing routine.
// Every drawing starts here.
void onDraw(unsigned long currentTime) {
  if (!isDisplayTime(currentTime))   // Do not re-draw at every tick
    return;

  if (displayMode == DISPLAY_MODE_START_UP) {
    drawStartUp();
  }
  else if (displayMode == DISPLAY_MODE_CLOCK) {
    if (isClicked == LOW) {   // User input received
      startEmergencyMode();
      setPageChangeTime(0);    // Change mode with no page-delay
      setNextDisplayTime(currentTime, 0);    // Do not wait next re-draw time
    }
    else {
      drawClock();

      if (isPageChangeTime(currentTime)) { // It's time to go into idle mode
        startIdleMode();
        setPageChangeTime(currentTime);  // Set a short delay
      }
      setNextDisplayTime(currentTime, CLOCK_DISP_INTERVAL);
    }
  }
  else if (displayMode == DISPLAY_MODE_EMERGENCY_MSG) {
    if (findNextEmerMessage()) {
      drawEmergency();
      emgCurDisp++;
      if (emgCurDisp >= EMG_COUNT_MAX) {
        emgCurDisp = 0;
        startMessageMode();
      }
      setNextDisplayTime(currentTime, EMERGENCY_DISP_INTERVAL);
    }
    // There's no message left to display. Go to normal message mode.
    else {
      startMessageMode();
      //setPageChangeTime(0);
      setNextDisplayTime(currentTime, 0);  // with no re-draw interval
    }
  }
  else if (displayMode == DISPLAY_MODE_NORMAL_MSG) {
    if (findNextNormalMessage()) {
      drawMessage();
      msgCurDisp++;
      if (msgCurDisp >= MSG_COUNT_MAX) {
        msgCurDisp = 0;
        startClockMode();
      }
      setNextDisplayTime(currentTime, MESSAGE_DISP_INTERVAL);
    }
    // There's no message left to display. Go to clock mode.
    else {
      startClockMode();
      setPageChangeTime(currentTime);
      setNextDisplayTime(currentTime, 0);  // with no re-draw interval
    }
  }
  else if (displayMode == DISPLAY_MODE_IDLE) {
    if (isClicked == LOW) {   // Wake up watch if there's an user input
      startClockMode();
      setPageChangeTime(currentTime);
      setNextDisplayTime(currentTime, 0);
    }
    else {
      drawIdleClock();
      setNextDisplayTime(currentTime, IDLE_DISP_INTERVAL);
    }
  }
  else {
    startClockMode();    // This means there's an error
  }

  isClicked = HIGH;
}  // End of onDraw()


// To avoid re-draw on every drawing time
// wait for time interval according to current mode
// But user input(button) breaks this sleep
boolean isDisplayTime(unsigned long currentTime) {
  if (currentTime - prevDisplayTime > next_display_interval) {
    return true;
  }
  if (isClicked == LOW) {
    delay(500);
    return true;
  }
  return false;
}

// Set next re-draw time
void setNextDisplayTime(unsigned long currentTime, unsigned long nextUpdateTime) {
  next_display_interval = nextUpdateTime;
  prevDisplayTime = currentTime;
}

// Decide if it's the time to change page(mode)
boolean isPageChangeTime(unsigned long currentTime) {
  if (displayMode == DISPLAY_MODE_CLOCK) {
    if (currentTime - mode_change_timer > CLOCK_DISPLAY_TIME)
      return true;
  }
  return false;
}

// Set time interval to next page(mode)
void setPageChangeTime(unsigned long currentTime) {
  mode_change_timer = currentTime;
}

// Check if available emergency message exists or not
boolean findNextEmerMessage() {
  if (emgCurDisp < 0 || emgCurDisp >= EMG_COUNT_MAX) emgCurDisp = 0;
  while (true) {
    if (emgBuffer[emgCurDisp][0] == 0x00) { // 0x00 means disabled
      emgCurDisp++;
      if (emgCurDisp >= EMG_COUNT_MAX) {
        emgCurDisp = 0;
        return false;
      }
    }
    else {
      break;
    }
  }  // End of while()
  return true;
}

// Check if available normal message exists or not
boolean findNextNormalMessage() {
  if (msgCurDisp < 0 || msgCurDisp >= MSG_COUNT_MAX) msgCurDisp = 0;
  while (true) {
    if (msgBuffer[msgCurDisp][0] == 0x00) {
      msgCurDisp++;
      if (msgCurDisp >= MSG_COUNT_MAX) {
        msgCurDisp = 0;
        return false;
      }
    }
    else {
      break;
    }
  }  // End of while()
  return true;
}

// Count all available emergency messages
int countEmergency() {
  int count = 0;
  for (int i = 0; i < EMG_COUNT_MAX; i++) {
    if (emgBuffer[i][0] != 0x00)
      count++;
  }
  return count;
}

// Count all available normal messages
int countMessage() {
  int count = 0;
  for (int i = 0; i < MSG_COUNT_MAX; i++) {
    if (msgBuffer[i][0] != 0x00)
      count++;
  }
  return count;
}

void startClockMode() {
  displayMode = DISPLAY_MODE_CLOCK;
}

void startEmergencyMode() {
  displayMode = DISPLAY_MODE_EMERGENCY_MSG;
  emgCurDisp = 0;
}

void startMessageMode() {
  displayMode = DISPLAY_MODE_NORMAL_MSG;
  msgCurDisp = 0;
}

void startIdleMode() {
  displayMode = DISPLAY_MODE_IDLE;
}

// Draw indicator. Indicator shows count of emergency and normal message
void drawIndicator() {
  if (updateIndicator) {
    int msgCount = countMessage();
    int emgCount = countEmergency();
    int drawCount = 1;

    if (msgCount > 0) {
      display.drawBitmap(127 - 8, 1, IMG_indicator_msg, 8, 8, WHITE);
      display.setTextColor(WHITE);
      display.setTextSize(1);
      display.setCursor(127 - 15, 1);
      display.print(msgCount);
      drawCount++;
    }

    if (emgCount > 0) {
      display.drawBitmap(127 - 8 * drawCount - 7 * (drawCount - 1), 1, IMG_indicator_emg, 8, 8, WHITE);
      display.setTextColor(WHITE);
      display.setTextSize(1);
      display.setCursor(127 - 8 * drawCount - 7 * drawCount, 1);
      display.print(emgCount);
    }

  }
}

// RetroWatch splash screen
void drawStartUp() {
  display.clearDisplay();

  display.drawBitmap(10, 15, IMG_logo_24x24, 24, 24, WHITE);

  display.setTextSize(2);
  display.setTextColor(WHITE);
  display.setCursor(45, 12);
  display.println("Retro");
  display.setCursor(45, 28);
  display.println("Watch");
  display.setTextSize(1);
  display.setCursor(45, 45);
  display.setTextColor(WHITE);
  display.println("Arduino v1.0");
  display.display();
  delay(2000);

  startClockMode();
}

// Draw emergency message page
void drawEmergency() {
  int icon_num = 60;
  display.clearDisplay();

  if (updateIndicator)
    drawIndicator();

  if (emgBuffer[emgCurDisp][2] > -1 && emgBuffer[emgCurDisp][2] < ICON_ARRAY_SIZE)
    icon_num = (int)(emgBuffer[emgCurDisp][2]);

  drawIcon(centerX - 8, centerY - 20, icon_num);

  display.setTextColor(WHITE);
  display.setTextSize(1);
  display.setCursor(getCenterAlignedXOfEmg(emgCurDisp), centerY + 10);
  for (int i = 3; i < EMG_BUFFER_MAX; i++) {
    char curChar = emgBuffer[emgCurDisp][i];
    if (curChar == 0x00) break;
    if (curChar >= 0xf0) continue;
    display.write(curChar);
  }

  display.display();
}

// Draw normal message page
void drawMessage() {
  int icon_num = 0;
  display.clearDisplay();

  if (updateIndicator)
    drawIndicator();

  if (msgBuffer[msgCurDisp][2] > -1 && msgBuffer[msgCurDisp][2] < ICON_ARRAY_SIZE)
    icon_num = (int)(msgBuffer[msgCurDisp][2]);

  drawIcon(centerX - 8, centerY - 20, icon_num);

  display.setTextColor(WHITE);
  display.setTextSize(1);
  display.setCursor(getCenterAlignedXOfMsg(msgCurDisp), centerY + 10);
  //  display.print(msgCurDisp);  // For debug
  for (int i = 3; i < MSG_BUFFER_MAX; i++) {
    char curChar = msgBuffer[msgCurDisp][i];
    if (curChar == 0x00) break;
    if (curChar >= 0xf0) continue;
    display.write(curChar);
  }

  display.display();
}
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

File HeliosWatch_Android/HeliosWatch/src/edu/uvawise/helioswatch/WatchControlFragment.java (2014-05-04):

/*
 * Copyright (C) 2014 The Retro Watch - Open source smart watch project
 *
 * Licensed under the Apache License, Version 2.0 (the "License");
 * you may not use this file except in compliance with the License.
 * You may obtain a copy of the License at
 *
 *      http://www.apache.org/licenses/LICENSE-2.0
 *
 * Unless required by applicable law or agreed to in writing, software
 * distributed under the License is distributed on an "AS IS" BASIS,
 * WITHOUT WARRANTIES OR CONDITIONS OF ANY KIND, either express or implied.
 * See the License for the specific language governing permissions and
 * limitations under the License.
 */

package edu.uvawise.helioswatch;

import edu.uvawise.helioswatch.utils.Settings;

import android.content.Context;
import android.os.Bundle;
import android.support.v4.app.Fragment;
import android.text.Editable;
import android.text.TextWatcher;
import android.view.LayoutInflater;
import android.view.View;
import android.view.ViewGroup;
import android.widget.AdapterView;
import android.widget.ArrayAdapter;
import android.widget.EditText;
import android.widget.Spinner;
import android.widget.AdapterView.OnItemSelectedListener;

/**
 * This fragment shows user defined message filters.
 */
public class WatchControlFragment extends Fragment {

	private Context mContext = null;
	private IFragmentListener mFragmentListener = null;
	
	private EditText mEditGmailAddr = null;
	private Spinner mSpinnerClockStyle = null;
	private Spinner mSpinnerIndicator = null;
    private Spinner mSpinnerMotor = null;
	
	private int mPresetClockStyle = -1;
	private int mPresetIndicator = -1;

	public WatchControlFragment(Context c, IFragmentListener l) {
		mContext = c;
		mFragmentListener = l;
	}

	@Override
	public View onCreateView(LayoutInflater inflater, ViewGroup container, Bundle savedInstanceState) {
		View rootView = inflater.inflate(R.layout.fragment_watch_control, container, false);
		
		mEditGmailAddr = (EditText) rootView.findViewById(R.id.edit_email_addr);
		String defaultAddr = Settings.getInstance(mContext).getGmailAddress();
		if(defaultAddr != null && !defaultAddr.isEmpty())
			mEditGmailAddr.setText(defaultAddr);
		mEditGmailAddr.addTextChangedListener(new TextWatcher() {
			@Override
			public void onTextChanged(CharSequence s, int start, int before, int count) {
				String addr = s.toString();
				if(addr != null && !addr.isEmpty()) {
					mFragmentListener.OnFragmentCallback(IFragmentListener.CALLBACK_REQUEST_SET_EMAIL_ADDRESS, 
							0, 0, addr, null, null);
				}
			}
			@Override public void beforeTextChanged(CharSequence s, int start, int count,int after) {}
			@Override public void afterTextChanged(Editable s) {}
		});
		
		mSpinnerClockStyle = (Spinner) rootView.findViewById(R.id.spinner_clock_style);
		ArrayAdapter<CharSequence> adapter = ArrayAdapter.createFromResource(mContext, 
				R.array.clock_style_array, 
				R.layout.spinner_simple_item2);
		adapter.setDropDownViewResource(R.layout.spinner_dropdown_simple_item);
		mSpinnerClockStyle.setPrompt(mContext.getString(R.string.clock_style_title));
		mSpinnerClockStyle.setAdapter(adapter);
		mSpinnerClockStyle.setOnItemSelectedListener(new OnItemSelectedListener() {
			@Override
			public void onItemSelected(AdapterView<?> parent, View view, int position, long id) {
				if(mPresetClockStyle > -1 && mPresetClockStyle != position) {
					mFragmentListener.OnFragmentCallback(IFragmentListener.CALLBACK_REQUEST_CLOCK_STYLE, 
							position+1, 0, null, null, null);
				}
				mPresetClockStyle = position;
			}
			@Override
			public void onNothingSelected(AdapterView<?> arg0) {}
		});
		
		mSpinnerIndicator = (Spinner) rootView.findViewById(R.id.spinner_show_indicator);
        ArrayAdapter<CharSequence> adapter2 = ArrayAdapter.createFromResource(mContext,
                R.array.clock_indicator_array,
                R.layout.spinner_simple_item2);
        adapter2.setDropDownViewResource(R.layout.spinner_dropdown_simple_item);
        mSpinnerIndicator.setPrompt(mContext.getString(R.string.clock_indicator_title));
        mSpinnerIndicator.setAdapter(adapter2);
        mSpinnerIndicator.setOnItemSelectedListener(new OnItemSelectedListener() {
            @Override
            public void onItemSelected(AdapterView<?> parent, View view, int position, long id) {
                if(mPresetIndicator > -1 && mPresetIndicator != position) {
                    mFragmentListener.OnFragmentCallback(IFragmentListener.CALLBACK_REQUEST_SHOW_INDICATOR,
                            position+1, 0, null, null, null);
                }
                mPresetIndicator = position;
            }
            @Override
            public void onNothingSelected(AdapterView<?> arg0) {}
        });

        mSpinnerMotor = (Spinner) rootView.findViewById(R.id.spinner_vibration_motor);
        ArrayAdapter<CharSequence> adapter3 = ArrayAdapter.createFromResource(mContext,
                R.array.vibration_motor_array,
                R.layout.spinner_simple_item2);
        adapter3.setDropDownViewResource(R.layout.spinner_dropdown_simple_item);
        mSpinnerMotor.setPrompt(mContext.getString(R.string.vibration_motor_title));
        mSpinnerMotor.setAdapter(adapter3);
        mSpinnerMotor.setOnItemSelectedListener(new OnItemSelectedListener() {
            @Override
            public void onItemSelected(AdapterView<?> parent, View view, int position, long id) {
                if(mPresetIndicator > -1 && mPresetIndicator != position) {
                    mFragmentListener.OnFragmentCallback(IFragmentListener.CALLBACK_REQUEST_VIBRATE_MOTOR,
                            position+1, 0, null, null, null);
                }
                mPresetIndicator = position;
            }
            @Override
            public void onNothingSelected(AdapterView<?> arg0) {}
        });
		
		return rootView;
	}
	
	
}

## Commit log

2014-04-22 Add the logo and project diagram.
    [HeliosWatchDiagram.fzz]
2014-04-23 Update README.md
    Because apparently GitHub's Clone URL button for the Wiki gives you the wrong URL...
2014-04-24 Update wiring diagram.
    [HeliosWatchDiagram.fzz]
2014-04-25 Add some guide images. Prep and power supply.
2014-04-27 Implement vibration motor.
2014-05-04 Update UI Strings and Add Vibration Motor Control
    [WatchControlFragment.java]
2014-05-04 Arduino: Add vibration motor toggle logic.
    [HeliosWatchArduino.ino]
2014-05-06 Add the 3D Printing files for the case.
    [HeliosCase.skp, HeliosCase.stl]
2014-05-06 Fixed a derp in the case model.
    [HeliosCase.skp, HeliosCase.stl]
2014-05-06 Add case images.

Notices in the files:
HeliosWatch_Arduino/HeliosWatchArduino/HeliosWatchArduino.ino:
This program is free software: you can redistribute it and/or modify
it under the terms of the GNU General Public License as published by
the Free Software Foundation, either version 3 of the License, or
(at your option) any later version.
